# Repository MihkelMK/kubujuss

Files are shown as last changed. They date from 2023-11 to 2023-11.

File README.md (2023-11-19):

# kubujuss WIP
This is my second custom keyboard. I started with a Keychron K2 with lubed Gateron Yellows and a custom slimmer case without the battery. It has served me well but the barrage of keyboard content has slowly built up the urge to make another one.

Typically there seems to be some keyboard inbetween a 75% layout and minimal split keyboard, but the soothing and dangerously approachable videos of Ben Wallok have radicalised me beyond repair.

## So here we are
34 keys split into 2 seperate halves.

Column stagger was adjusted by eye to match some illustrations and mockups I made on paper.

I found the pinkie cluster idea on accient, when I tried to find images of split keyboards on google. I found an image of [Wubbo](https://github.com/cacheworks/Wubbo). It seemed weird at first but the first tests on paper seemed promising. Time will tell if it works in real life as well.

## Thanks
Big thanks for [FlatFootFox](https://flatfootfox.com/) for his awesome [introduction to ergogen v4](https://flatfootfox.com/ergogen-introduction/). This guide taught me everything I know about ergogen and kicad.

And a gigantic thanks for @christianselig, for helping me figure out how to make both PCB halves in one ergogen file.

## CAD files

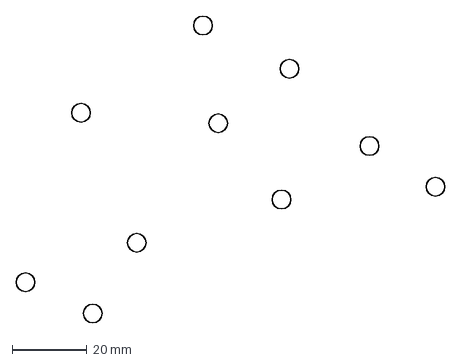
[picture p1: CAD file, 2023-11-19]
output/outlines/standoff2.dxf
114.3 x 81.8 mm

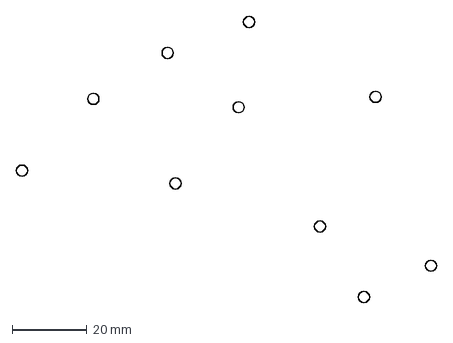
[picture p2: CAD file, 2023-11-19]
output/outlines/mounting.dxf
112.3 x 76.5 mm

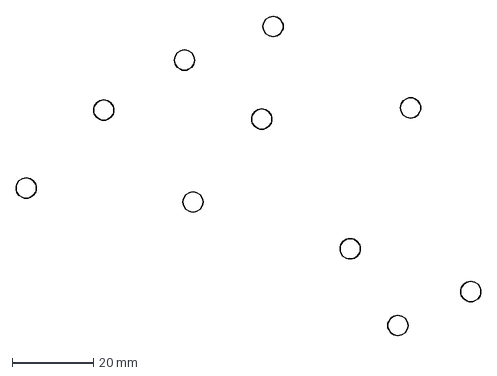
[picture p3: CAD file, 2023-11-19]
output/outlines/standoff.dxf
114.3 x 78.5 mm

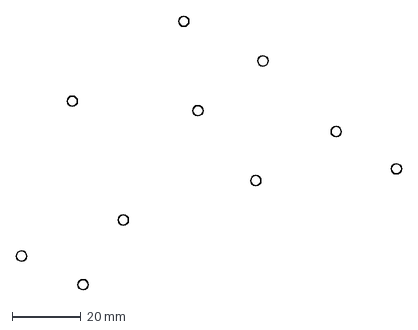
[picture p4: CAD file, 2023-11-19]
output/outlines/mounting2.dxf
112.3 x 79.8 mm

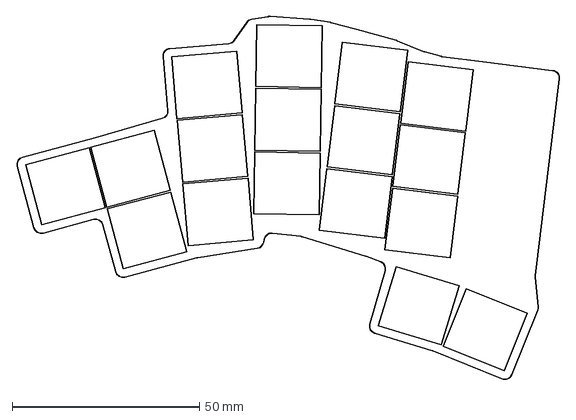
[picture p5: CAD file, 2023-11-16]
output/outlines/combo.dxf
145.0 x 96.9 mm

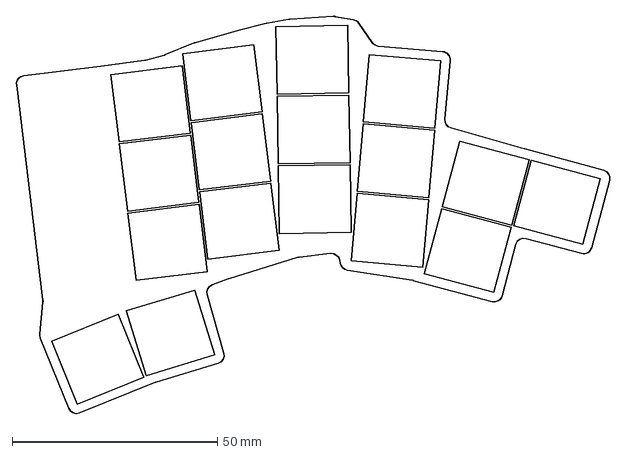
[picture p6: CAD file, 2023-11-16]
output/outlines/combo2.dxf
145.0 x 97.1 mm

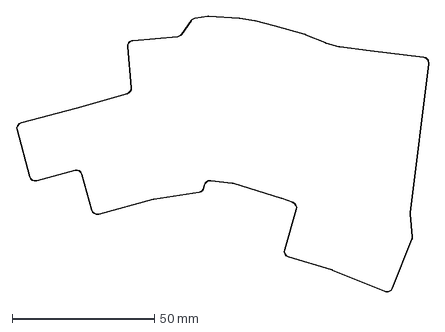
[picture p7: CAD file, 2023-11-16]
output/outlines/board.dxf
145.0 x 96.9 mm

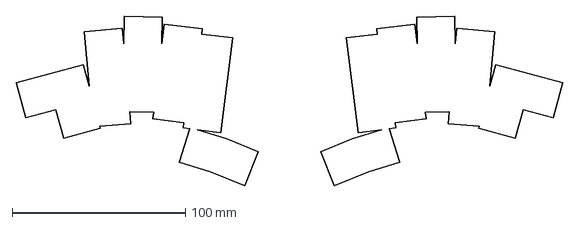
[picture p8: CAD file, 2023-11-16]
output/outlines/raw.dxf
314.9 x 97.6 mm

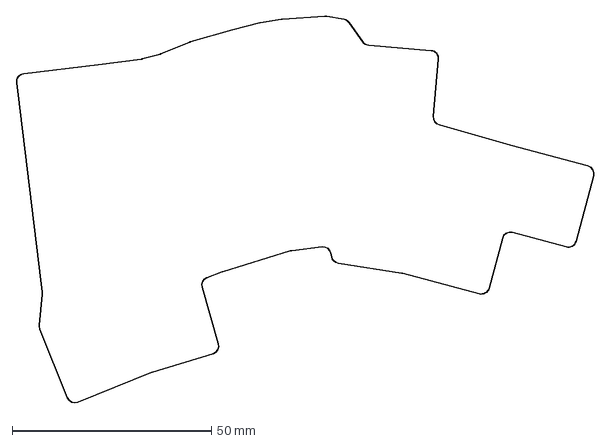
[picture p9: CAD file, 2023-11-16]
output/outlines/board2.dxf
145.0 x 97.1 mm

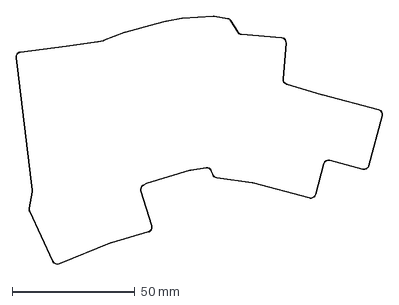
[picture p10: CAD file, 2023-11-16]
output/outlines/xlBoard2.dxf
149.6 x 101.3 mm

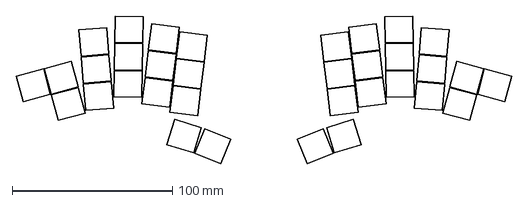
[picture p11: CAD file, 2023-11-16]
output/outlines/keys.dxf
309.4 x 92.3 mm

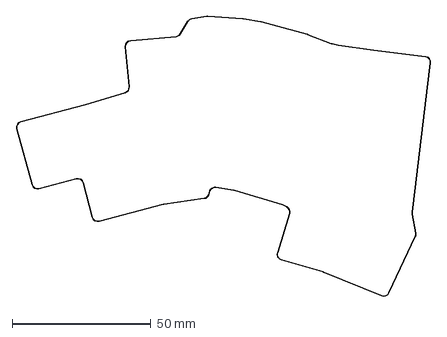
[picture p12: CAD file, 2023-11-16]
output/outlines/xlBoard.dxf
149.6 x 101.3 mm

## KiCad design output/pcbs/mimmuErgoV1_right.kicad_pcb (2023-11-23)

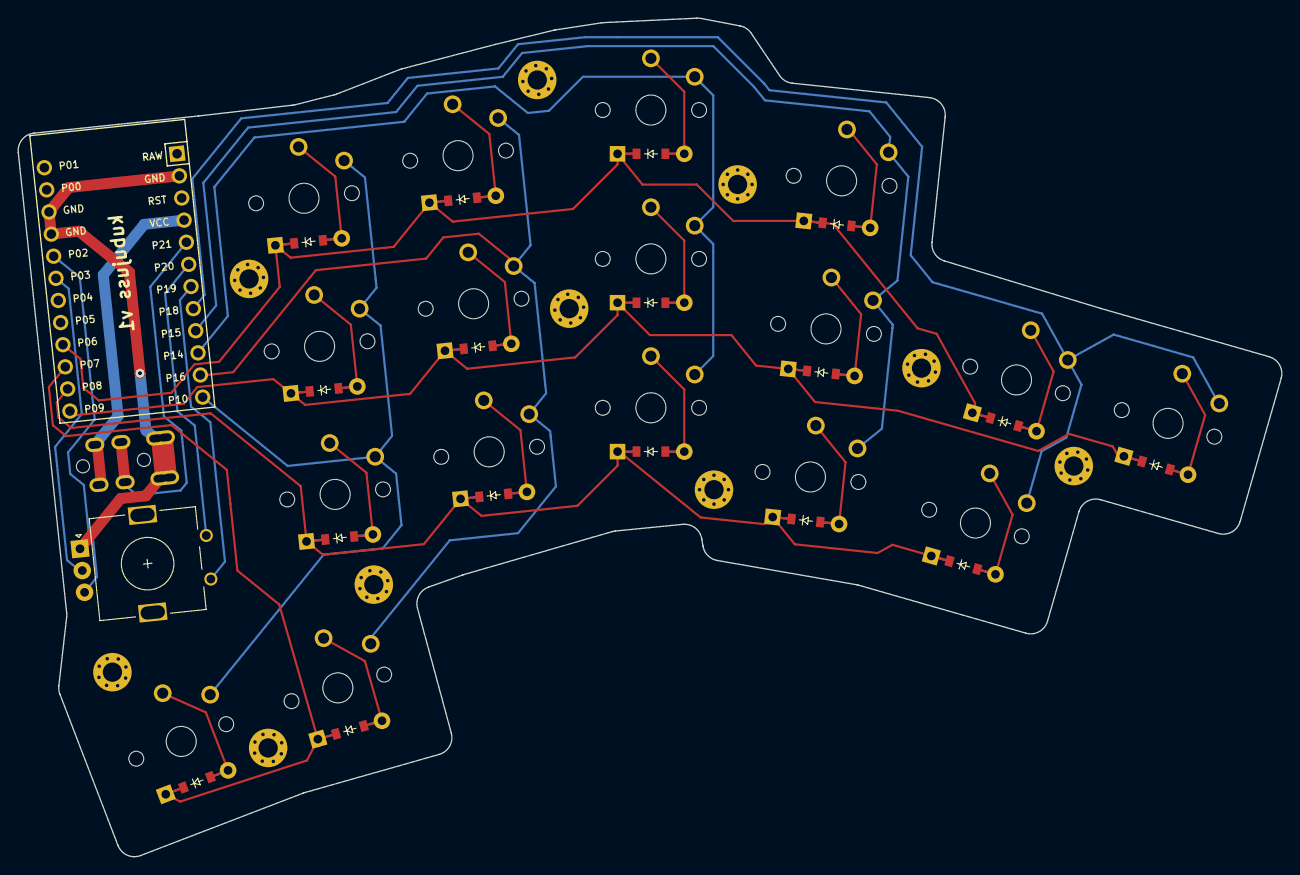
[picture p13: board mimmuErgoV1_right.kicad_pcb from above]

Board: 2 copper layers, 144.3 x 95.7 mm, 47 parts (0 on the bottom side), 33 nets.

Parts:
D1, D2, D3, D4, D5, D6, D7, D8, D9, D10, D11, D12, D13, D14, D15, D16, D17: ComboDiode
MCU1: ProMicro
ROT1: rotary_encoder
S1, S2, S3, S4, S5, S6, S7, S8, S9, S10, S11, S12, S13, S14, S15, S16, S17: PG1350
TRRS1: TRRS-PJ-320A-dual
_1, _2, _3, _4, _5, _6, _7, _8, _9, _10: MountingHole_2.2mm_M2_Pad_Via

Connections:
GND: MCU1.2, MCU1.15, MCU1.16, ROT1.A, TRRS1.1, TRRS1.2
P2: MCU1.17, ROT1.B
P3: MCU1.18, ROT1.C
P6: D2.1, D6.1, D9.1, D12.1, D15.1, MCU1.21
P7: D16.1, D17.1, MCU1.22
P8: D1.1, D4.1, D7.1, D10.1, D13.1, MCU1.23
P9: D3.1, D5.1, D8.1, D11.1, D14.1, MCU1.24
P10: MCU1.12, S13.1, S14.1, S15.1, S17.1
P14: MCU1.10, S7.1, S8.1, S9.1
P15: MCU1.9, S4.1, S5.1, S6.1
P16: MCU1.11, S10.1, S11.1, S12.1, S16.1
P18: MCU1.8, S1.1, S2.1, S3.1
P19: MCU1.7, ROT1.2
P20: MCU1.6, ROT1.1
P21: MCU1.5, TRRS1.3
VCC: MCU1.4, TRRS1.4
mirror_index_bottom: D10.2, S10.2
mirror_index_home: D11.2, S11.2
mirror_index_top: D12.2, S12.2
mirror_inner_bottom: D13.2, S13.2
mirror_inner_home: D14.2, S14.2
mirror_inner_top: D15.2, S15.2
mirror_layer_cluster: D16.2, S16.2
mirror_middle_bottom: D7.2, S7.2
mirror_middle_home: D8.2, S8.2
mirror_middle_top: D9.2, S9.2
mirror_pinkie_bottom: D1.2, S1.2
mirror_pinkie_home: D2.2, S2.2
mirror_pinkie_top: D3.2, S3.2
mirror_ring_bottom: D4.2, S4.2
mirror_ring_home: D5.2, S5.2
mirror_ring_top: D6.2, S6.2
mirror_space_cluster: D17.2, S17.2

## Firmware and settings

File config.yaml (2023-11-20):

units:
  # Proxy Spacing Variables
  kx: cx
  ky: cy
  # Padding Variables
  px: kx + 4
  py: ky + 4
  # Double Padding Variables
  dpx: kx + 8
  dpy: ky + 8
  # M2 Screw Inserts
  screwSize: 1.5
  standoffSize: 2.5
points:
  zones:
    matrix:
      # Fix placement on KiCAD sheet.
      anchor:
        shift: [50, -200]
      key:
        padding: 1ky
        spread: 1kx
      columns:
        pinkie:
          rows.top:
            shift: [-kx,-ky]
            width: 1.5kx
            row_net: P9
          rows.home:
            row_net: P6
          key:
            column_net: P18
        ring:
          key:
            splay: -10
            origin: [0, -kx/2]
            column_net: P15
        middle:
          key:
            stagger: 6
            splay: -6
            origin: [0, -kx/2]
            column_net: P14
        index:
          key:
            stagger: -5
            splay: -6
            origin: [0, -kx/4]
            column_net: P16
        inner:
          key:
            stagger: -3
            column_net: P10
      rows:
        bottom:
          row_net: P8
        home:
          row_net: P9
        top:
          row_net: P6
    thumbs:
      key:
        padding: 1ky
        spread: 1kx
      anchor:
        ref: matrix_inner_bottom
        shift: [2, -22]
      columns:
        layer:
          key:
            splay: -10
            column_net: P16
        space:
          key:
            stagger: -1
            splay: -5
            origin: [1, -10]
            column_net: P10
      rows:
        cluster:
          row_net: P7
  rotate: 15
  mirror: &mirror
    ref: matrix_inner_top
    distance: 5kx
outlines:
  raw:
    - what: rectangle
      where: true
      size: [px, py]
  keys:
    - what: rectangle
      where: true
      size: [kx-0.5, ky-0.5]
  board:
    - what: polygon
      operation: stack
      points:
        - ref: matrix_pinkie_top
          shift: [-0.5px, 0.5py]
        - ref: matrix_pinkie_top
          shift: [0.5px, 0.5py]
        - ref: matrix_ring_home
          shift: [-0.5px, 0.45py]
        - ref: matrix_ring_top
          shift: [-0.5px, 0.5py]
        - ref: matrix_ring_top
          shift: [-0.25px, 0.5py]
        - ref: matrix_ring_top
          shift: [0.35px, 0.5py]
        - ref: matrix_middle_top
          shift: [-0.5px, 0.45py]
        - ref: matrix_middle_top
          shift: [-0.25px, 0.5py]
        - ref: matrix_middle_top
          shift: [0.25px, 0.475py]
        - ref: matrix_middle_top
          shift: [0.5px, 0.435py]
        - ref: matrix_index_top
          shift: [-0.25px, 0.58py]
        - ref: matrix_index_top
          shift: [0.25px, 0.5py]
        - ref: matrix_index_top
          shift: [0.6px, 0.4py]
        - ref: matrix_inner_top
          shift: [0, 0.51py]
        - ref: matrix_inner_top
          shift: [0.5px, 0.505py]
        - ref: matrix_inner_home
          shift: [1.45px, 1.315py]
        - ref: matrix_inner_bottom
          shift: [1.45px, -0.5py]
        - ref: thumbs_space_cluster
          shift: [0.5px, 0.5py] 
        - ref: thumbs_space_cluster
          shift: [0.5px, -0.5py]
        - ref: thumbs_space_cluster
          shift: [-0.5px,-0.5py]
        - ref: thumbs_layer_cluster
          shift: [-0.5px,-0.5py]
        - ref: matrix_inner_bottom
          shift: [-0.35px, -0.575py]
        - ref: matrix_index_bottom
          shift: [0.2px, -0.65py]
        - ref: matrix_index_bottom
          shift: [-0.6px, -0.5py]
        - ref: matrix_middle_bottom
          shift: [-0.25px, -0.625py]
        - ref: matrix_ring_bottom
          shift: [0.5px, -0.5py]
        - ref: matrix_pinkie_bottom
          shift: [0.5px,-0.5py]
        - ref: matrix_pinkie_bottom
          shift: [-0.5px,-0.5py]
        - ref: matrix_pinkie_home
          shift: [-0.5px,-0.5py]
        - ref: matrix_pinkie_top
          shift: [-0.5px,-0.5py]
      fillet: 2
  xlBoard:
    - what: polygon
      operation: stack
      points:
        - ref: matrix_pinkie_top
          shift: [-0.5dpx, 0.5dpy]
        - ref: matrix_pinkie_top
          shift: [0.5dpx, 0.5dpy]
        - ref: matrix_ring_home
          shift: [-0.5dpx, 0.45dpy]
        - ref: matrix_ring_top
          shift: [-0.5dpx, 0.5dpy]
        - ref: matrix_ring_top
          shift: [-0.25dpx, 0.5dpy]
        - ref: matrix_ring_top
          shift: [0.25dpx, 0.5dpy]
        - ref: matrix_middle_top
          shift: [-0.5dpx, 0.45dpy]
        - ref: matrix_middle_top
          shift: [-0.25dpx, 0.5dpy]
        - ref: matrix_middle_top
          shift: [0.25dpx, 0.475dpy]
        - ref: matrix_middle_top
          shift: [0.5dpx, 0.435dpy]
        - ref: matrix_index_top
          shift: [-0.25dpx, 0.58dpy]
        - ref: matrix_index_top
          shift: [0.25dpx, 0.5dpy]
        - ref: matrix_index_top
          shift: [0.6dpx, 0.41dpy]
        - ref: matrix_inner_top
          shift: [0, 0.52dpy]
        - ref: matrix_inner_top
          shift: [0.5dpx, 0.51dpy]
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

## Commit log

2023-11-16 add first draft
    [board.dxf, board2.dxf, combo.dxf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]
2023-11-23 Make GND and VCC traces 1mm thicker
    [mimmuErgoV1_left.kicad_pcb, mimmuErgoV1_right.kicad_pcb]
